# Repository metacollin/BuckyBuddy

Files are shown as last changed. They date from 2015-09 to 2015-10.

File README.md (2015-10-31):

# Cyclone V Bucky Buddy
<sub><sup><br /><span xmlns:dct="http://purl.org/dc/terms/" property="dct:title">Cyclone V Bucky Buddy</span> by <a xmlns:cc="http://creativecommons.org/ns#" href="https://github.com/metacollin/buckybuddy" property="cc:attributionName" rel="cc:attributionURL">metacollin</a> is licensed under a <a rel="license" href="http://creativecommons.org/licenses/by-nc-sa/4.0/">Creative Commons Attribution-NonCommercial-ShareAlike 4.0 International License</a>.</sup></sub>

BOM and component placement files are in the BOMAndPlace folder, shematics are in the Schematics folder. Board is available on [OSHpark](https://oshpark.com/shared_projects/RDkRPXU1).

The repository directory is a standard KiCad project and all CAD files are in KiCad format.

VRML Board

Schematic:
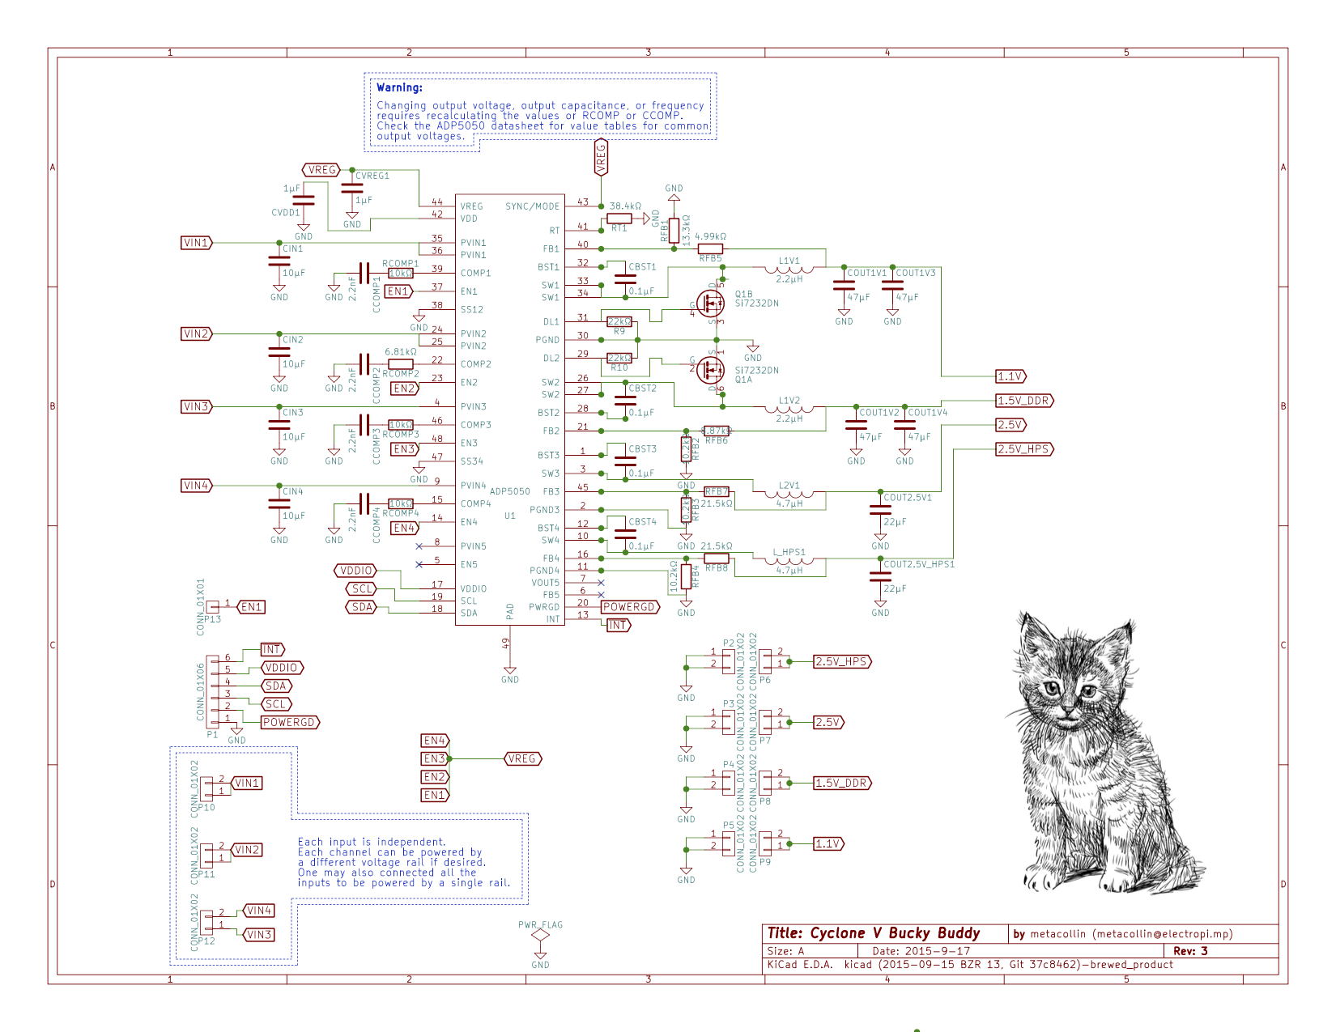
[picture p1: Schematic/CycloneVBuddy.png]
Schematic


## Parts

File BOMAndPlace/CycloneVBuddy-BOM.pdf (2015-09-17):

Id Designator | Package | Quantity Designation Part #
1 U1 | QFN-48-TE | 1 ADP5050 | ADP5050ACPZ
2 Q1 | PowerPak1212 | 1 Si7232DN Si7232DN || Si7228DN
3 RT1 | R_0402 | 1 38.4kΩ | Generic
4 RFB8,RFB7 | R_0402 | 2 21.5kΩ | Generic
5 RFB6 | R_0402 | 1 8.87kΩ | Generic
6 RFB5 | R_0402 | 1 4.99kΩ | Generic
7 RFB4,RFB3,RFB2 | R_0402 | 3 10.2kΩ | Generic
8 RFB1 | R_0402 | 1 13.3kΩ | Generic
9 RCOMP4,RCOMP3,RCOMP1 | R_0402 | 3 10kΩ | Generic
10 RCOMP2 | R_0402 | 1 6.81kΩ | Generic
11 R10,R9 | R_0402 | 2 22kΩ | Generic
12 CVREG1,CVDD1 | C_0402 | 2 1µF | GRM155R60J105KE19D
13 CCOMP4,CCOMP3,CCOMP2,CCOMP1 | C_0402 | 4 2.2nF | GRM155R61E222KA01D
14 CBST4,CBST3,CBST2,CBST1 | C_0402 | 4 0.1µF | GRM155R61C104KA88D
15 COUT2.5V_HPS1,COUT2.5V1 | C_0603 | 2 22µF | GRM188R60J226MEA0
16 COUT1V4,COUT1V3,COUT1V2,COUT1V1 C_0805 | 4 47µF | GRM21BR60J476ME15
17 CIN4,CIN3,CIN2,CIN1 | C_0805 | 4 10µF | GRM219R61E106KA12
18 L_HPS1,L2V1 | TYD6045 | 2 4.7µH | NRS4018T-4R7MDGJ
19 L1V2,L1V1 | TYD6045 | 2 2.2µH | NRS6045-2R3NMGK

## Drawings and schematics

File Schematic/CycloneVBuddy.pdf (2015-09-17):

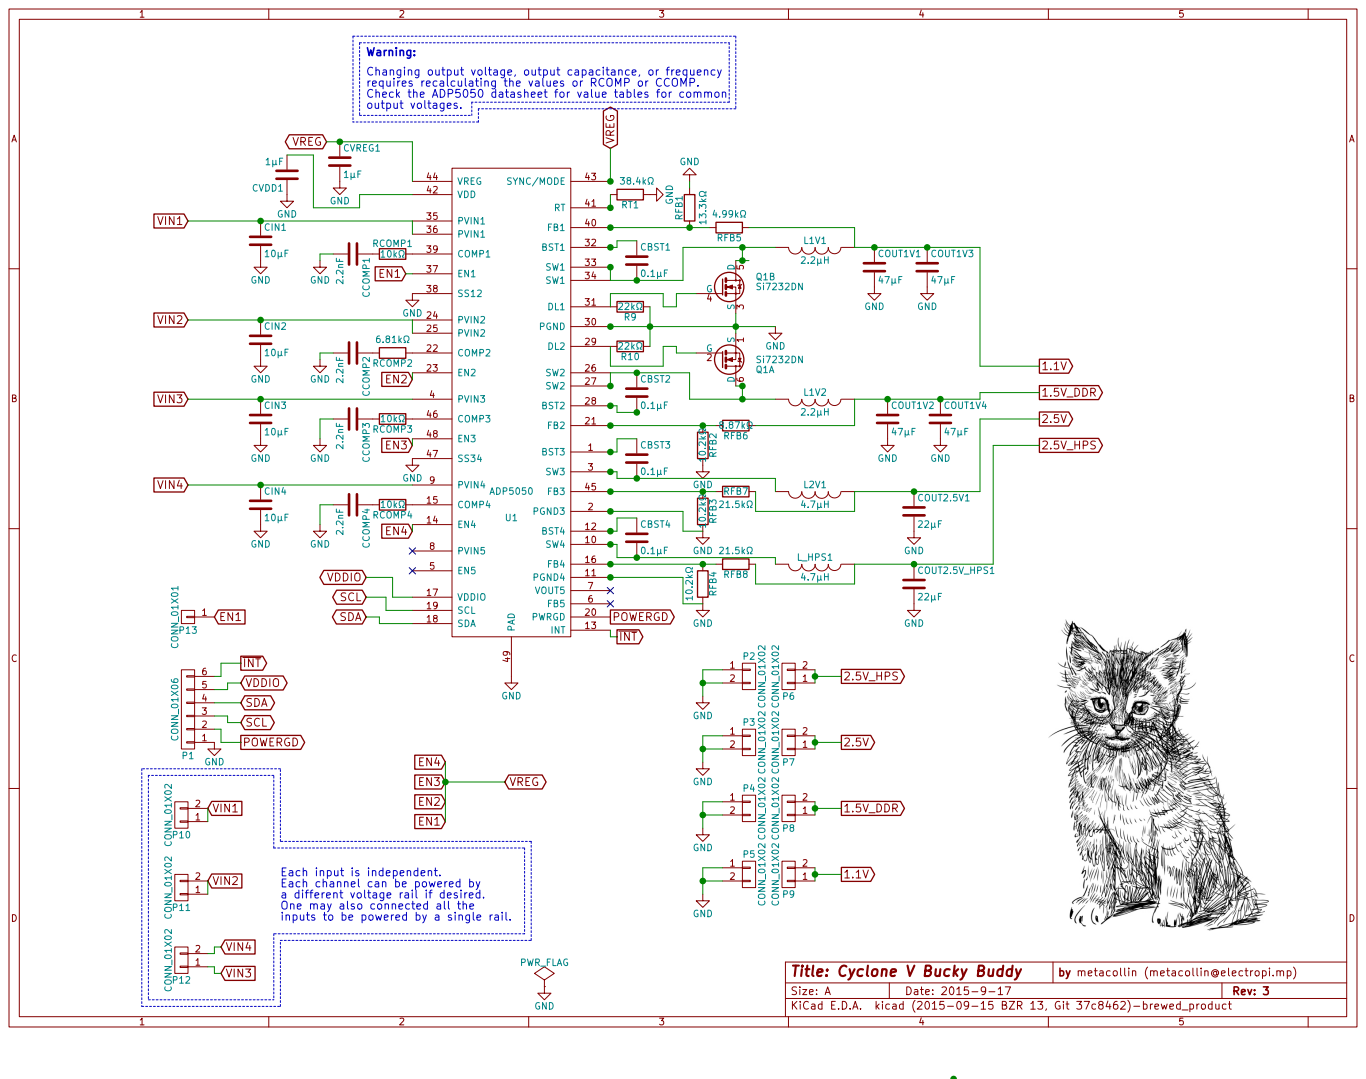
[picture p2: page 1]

Warning:
Changing output voltage, output capacitance, or frequency
requires recalculating the values or RCOMP or CCOMP.
Check the ADP5050 datasheet for value tables for common
output voltages.

2 P9 CONN_01X02 GND GND GND GND

Each channel can be powered by
a different voltage rail if desired.
One may also connected all the
inputs to be powered by a single rail.

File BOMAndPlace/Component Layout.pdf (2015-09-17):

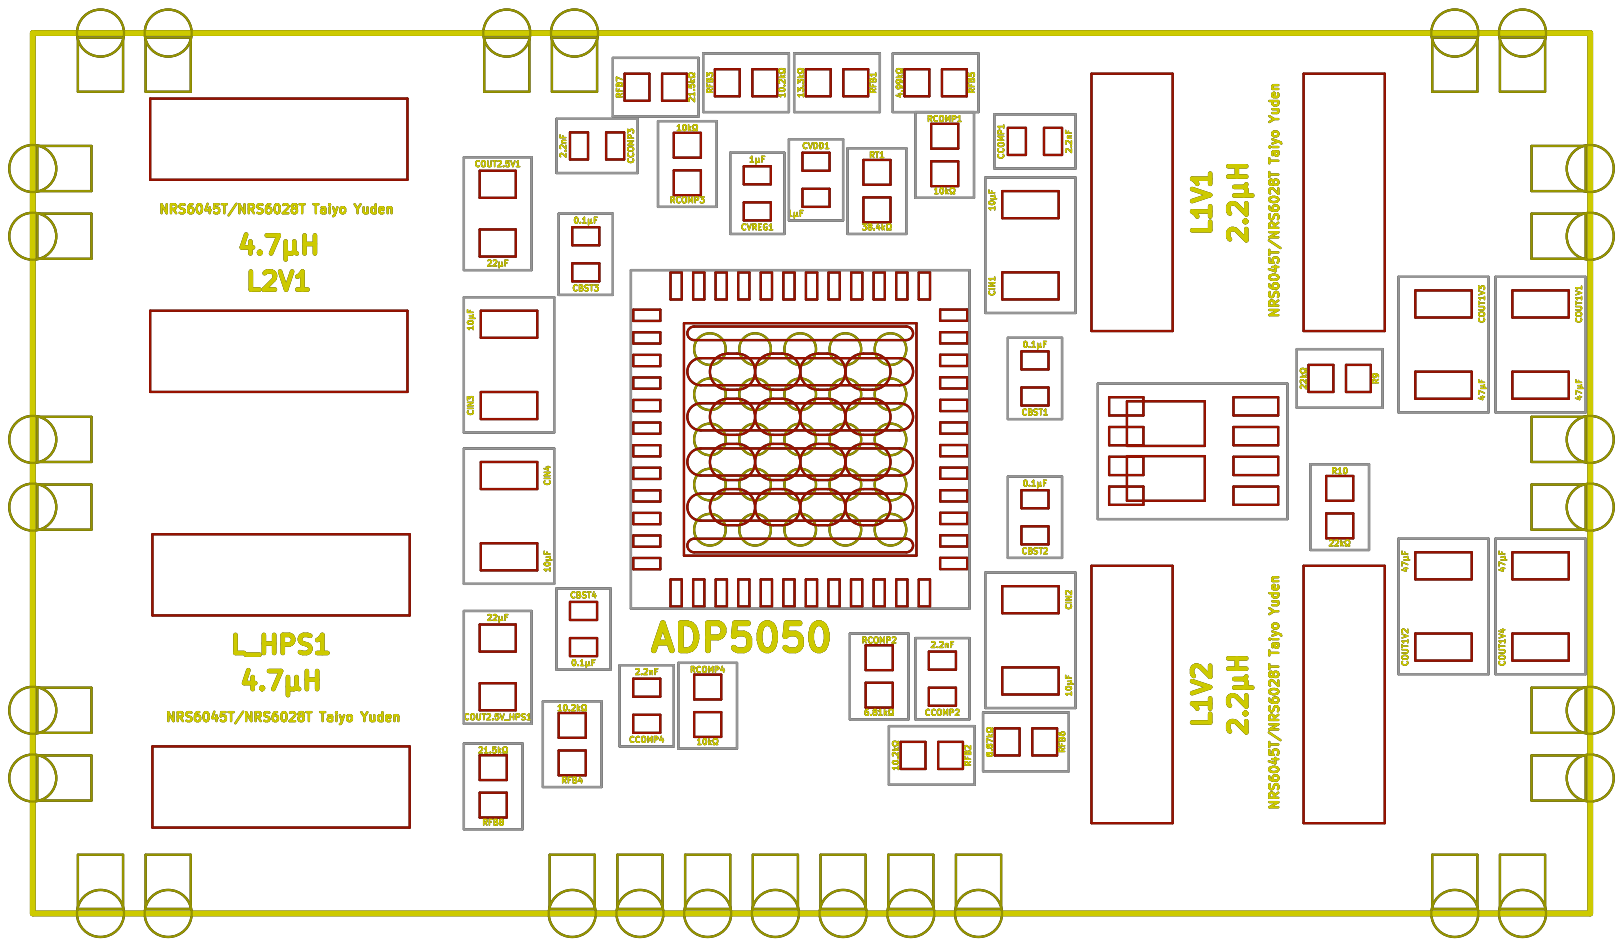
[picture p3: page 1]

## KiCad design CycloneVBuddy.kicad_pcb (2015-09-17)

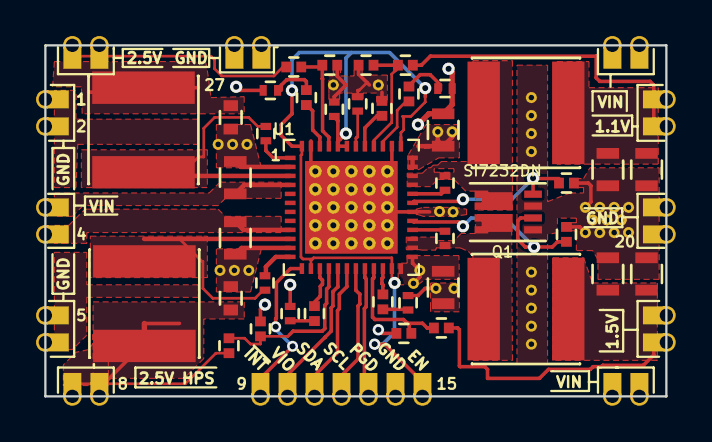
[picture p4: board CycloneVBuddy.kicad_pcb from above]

Board: 2 copper layers, 34.5 x 19.5 mm, 54 parts (1 on the bottom side), 39 nets.

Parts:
CBST1, CBST2, CBST3, CBST4: 0.1µF; C_0402
CCOMP1, CCOMP2, CCOMP3, CCOMP4: 2.2nF; C_0402
CIN1, CIN2, CIN3, CIN4: 10µF; C_0805
COUT1V1, COUT1V2, COUT1V3, COUT1V4: 47µF; C_0805
COUT2.5V1, COUT2.5V_HPS1: 22µF; C_0603
CVDD1: 1µF; C_0402
CVREG1: 1µF; C_0402
L1V1, L1V2: 2.2µH; TYD6045
L2V1: 4.7µH; TYD6045
L_HPS1: 4.7µH; TYD6045
P1: CONN_01X06; Castillated_6
P2, P3, P4, P5, P6, P7, P8, P9, P10, P11, P12: CONN_01X02; Castillated_2
P13: CONN_01X01; Castillated_1
Q1: Si7232DN; PowerPak1212
R9, R10: 22kΩ; R_0402
RCOMP1, RCOMP3, RCOMP4: 10kΩ; R_0402
RCOMP2: 6.81kΩ; R_0402
RFB1: 13.3kΩ; R_0402
RFB2, RFB3, RFB4: 10.2kΩ; R_0402
RFB5: 4.99kΩ; R_0402
RFB6: 8.87kΩ; R_0402
RFB7, RFB8: 21.5kΩ; R_0402
RT1: 38.4kΩ; R_0402
U1: ADP5050; QFN-48-TE

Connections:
1.1V: COUT1V1.1, COUT1V3.1, L1V1.1, P9.1, P9.2, RFB5.1
1.5V_DDR: COUT1V2.1, COUT1V4.1, L1V2.1, P8.1, P8.2, RFB6.1
2.5V: COUT2.5V1.1, L2V1.1, P7.1, P7.2, RFB7.1
2.5V_HPS: COUT2.5V_HPS1.1, L_HPS1.1, P6.1, P6.2, RFB8.1
EN1: CVREG1.1, P13.1, U1.14, U1.23, U1.37, U1.43, U1.44, U1.48
GND: CCOMP1.2, CCOMP2.2, CCOMP3.2, CCOMP4.2, CIN1.2, CIN2.2, CIN3.2, CIN4.2, COUT1V1.2, COUT1V2.2, COUT1V3.2, COUT1V4.2, COUT2.5V1.2, COUT2.5V_HPS1.2, CVDD1.1, CVREG1.2, P1.1, P2.1, P2.2, P3.1, P3.2, P4.1, P4.2, P5.1, P5.2, Q1.1, Q1.3, R9.1, R10.1, RFB1.2, RFB2.2, RFB3.2, RFB4.2, RT1.1, U1.2, U1.11, U1.30, U1.38, U1.47, U1.49
unnamed: CBST1.1, U1.32
unnamed: CBST1.2, L1V1.2, Q1.5, U1.33, U1.34
unnamed: CBST2.1, L1V2.2, Q1.6, U1.26, U1.27
unnamed: CBST2.2, U1.28
unnamed: CBST3.1, U1.1
unnamed: CBST3.2, L2V1.2, U1.3
unnamed: CBST4.1, U1.12
unnamed: CBST4.2, L_HPS1.2, U1.10
unnamed: CCOMP1.1, RCOMP1.1
unnamed: CCOMP2.1, RCOMP2.2
unnamed: CCOMP3.1, RCOMP3.2
unnamed: CCOMP4.1, RCOMP4.2
unnamed: CVDD1.2, U1.42
unnamed: Q1.2, R10.2, U1.29
unnamed: Q1.4, R9.2, U1.31
unnamed: RCOMP1.2, U1.39
unnamed: RCOMP2.1, U1.22
unnamed: RCOMP3.1, U1.46
unnamed: RCOMP4.1, U1.15
unnamed: RFB1.1, RFB5.2, U1.40
unnamed: RFB2.1, RFB6.2, U1.21
unnamed: RFB3.1, RFB7.2, U1.45
unnamed: RFB4.1, RFB8.2, U1.16
unnamed: RT1.2, U1.41
POWERGD: P1.2, U1.20
SCL: P1.3, U1.19
SDA: P1.4, U1.18
VDDIO: P1.5, U1.17
VIN1: CIN1.1, P10.1, P10.2, U1.35, U1.36
VIN2: CIN2.1, P11.1, P11.2, U1.24, U1.25
VIN3: CIN3.1, P12.1, U1.4
VIN4: CIN4.1, P12.2, U1.9
~INT: P1.6, U1.13

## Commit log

2015-09-17 Initial commit.
    [CycloneVBuddy-BOM.csv, CycloneVBuddy.kicad_pcb, CycloneVBuddy.sch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]
2015-09-18 Added Gerbers.
    [CycloneVBuddy-B_Cu.gbr, CycloneVBuddy-B_Mask.gbr, CycloneVBuddy-B_Paste.gbr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]
